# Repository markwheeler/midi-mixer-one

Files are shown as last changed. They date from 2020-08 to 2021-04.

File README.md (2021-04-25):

# MIDI Mixer One
MIDI Mixer One is a mixer-style USB MIDI controller built around Teensy.

[More info in the wiki](https://github.com/markwheeler/midi-mixer-one/wiki)

[Discussion thread on llllllll](https://llllllll.co/t/midi-mixer-one/35783)

Licensed under CC BY-NC-SA 4.0 (non-commercial use only).

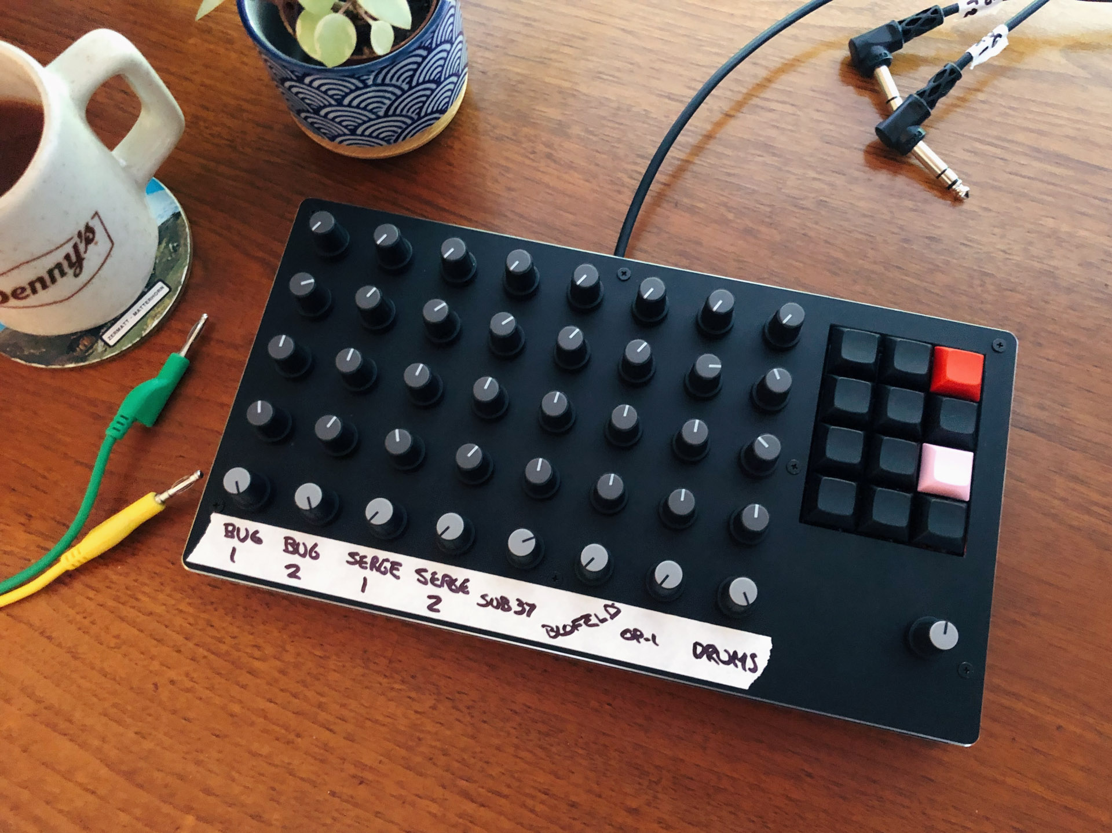
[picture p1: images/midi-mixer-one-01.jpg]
MIDI Mixer One photo


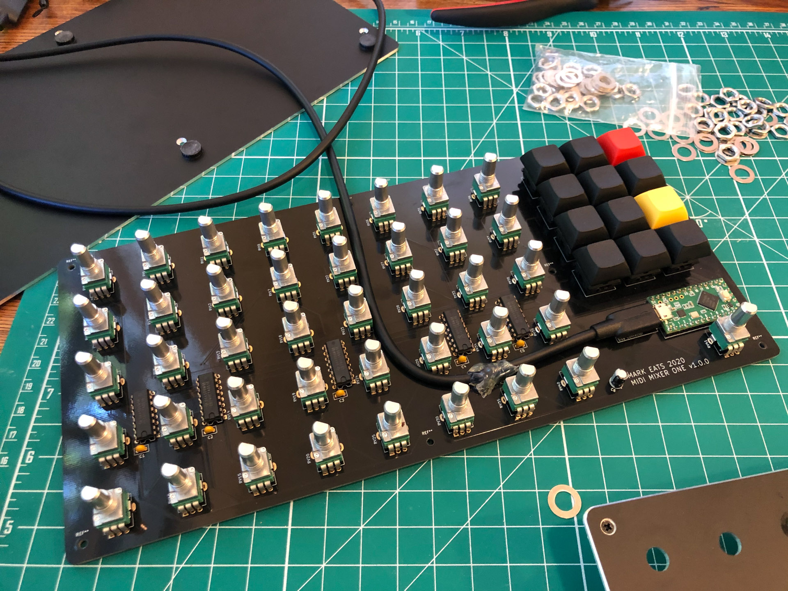
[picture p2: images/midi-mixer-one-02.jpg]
MIDI Mixer One build photo


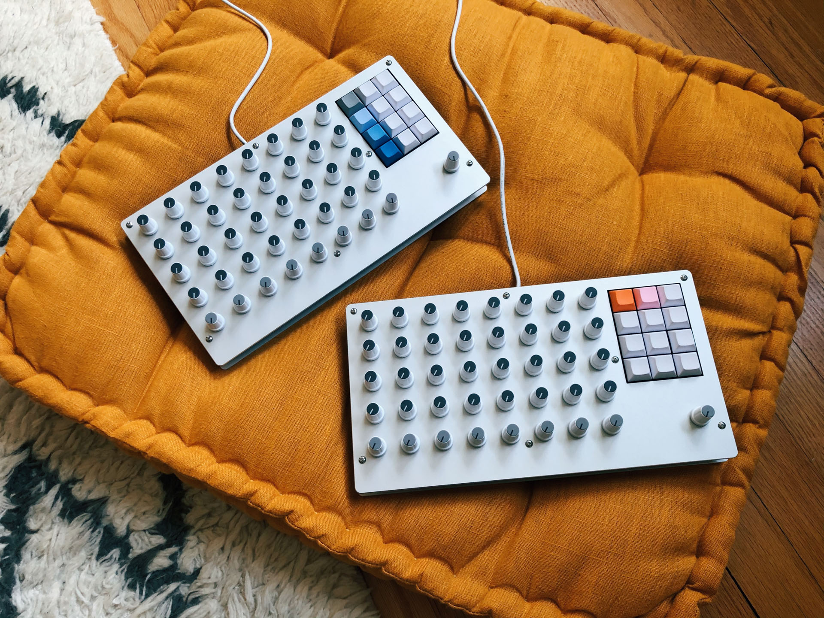
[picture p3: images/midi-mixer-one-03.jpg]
MIDI Mixer One photo


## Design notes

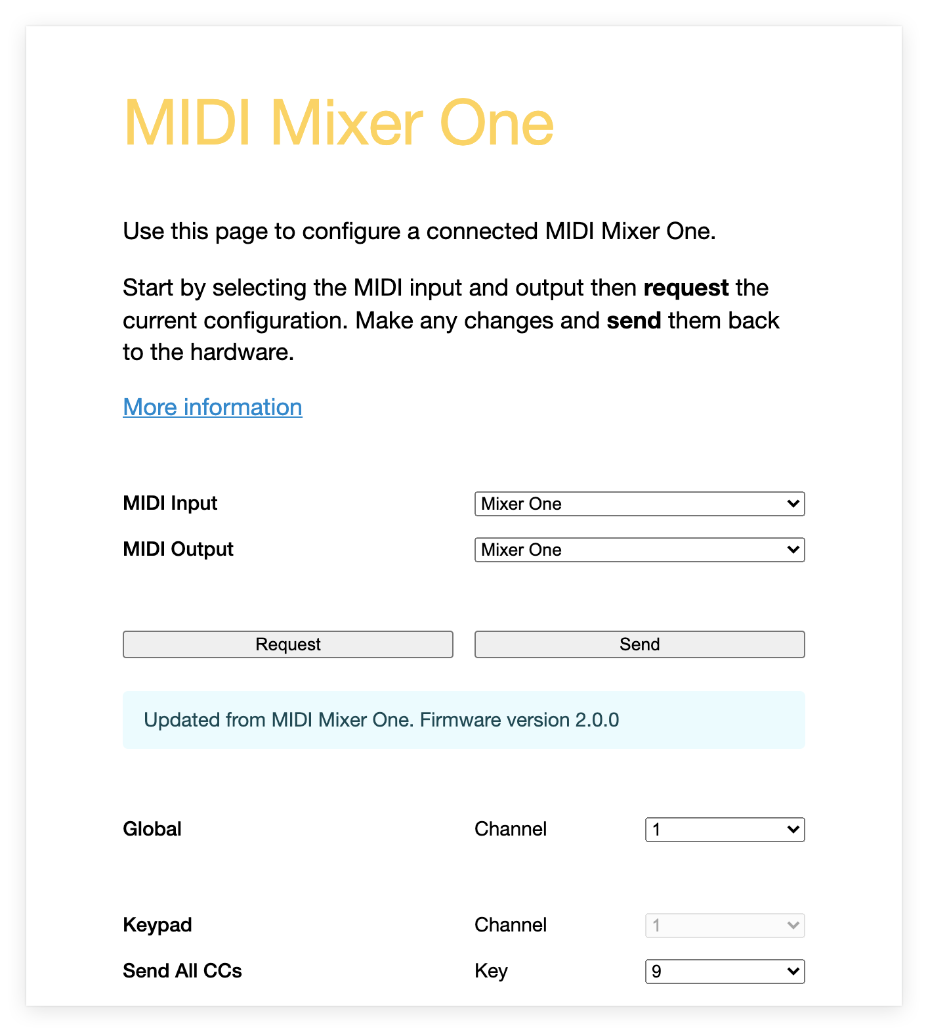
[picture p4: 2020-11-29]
images/web-config-01.png

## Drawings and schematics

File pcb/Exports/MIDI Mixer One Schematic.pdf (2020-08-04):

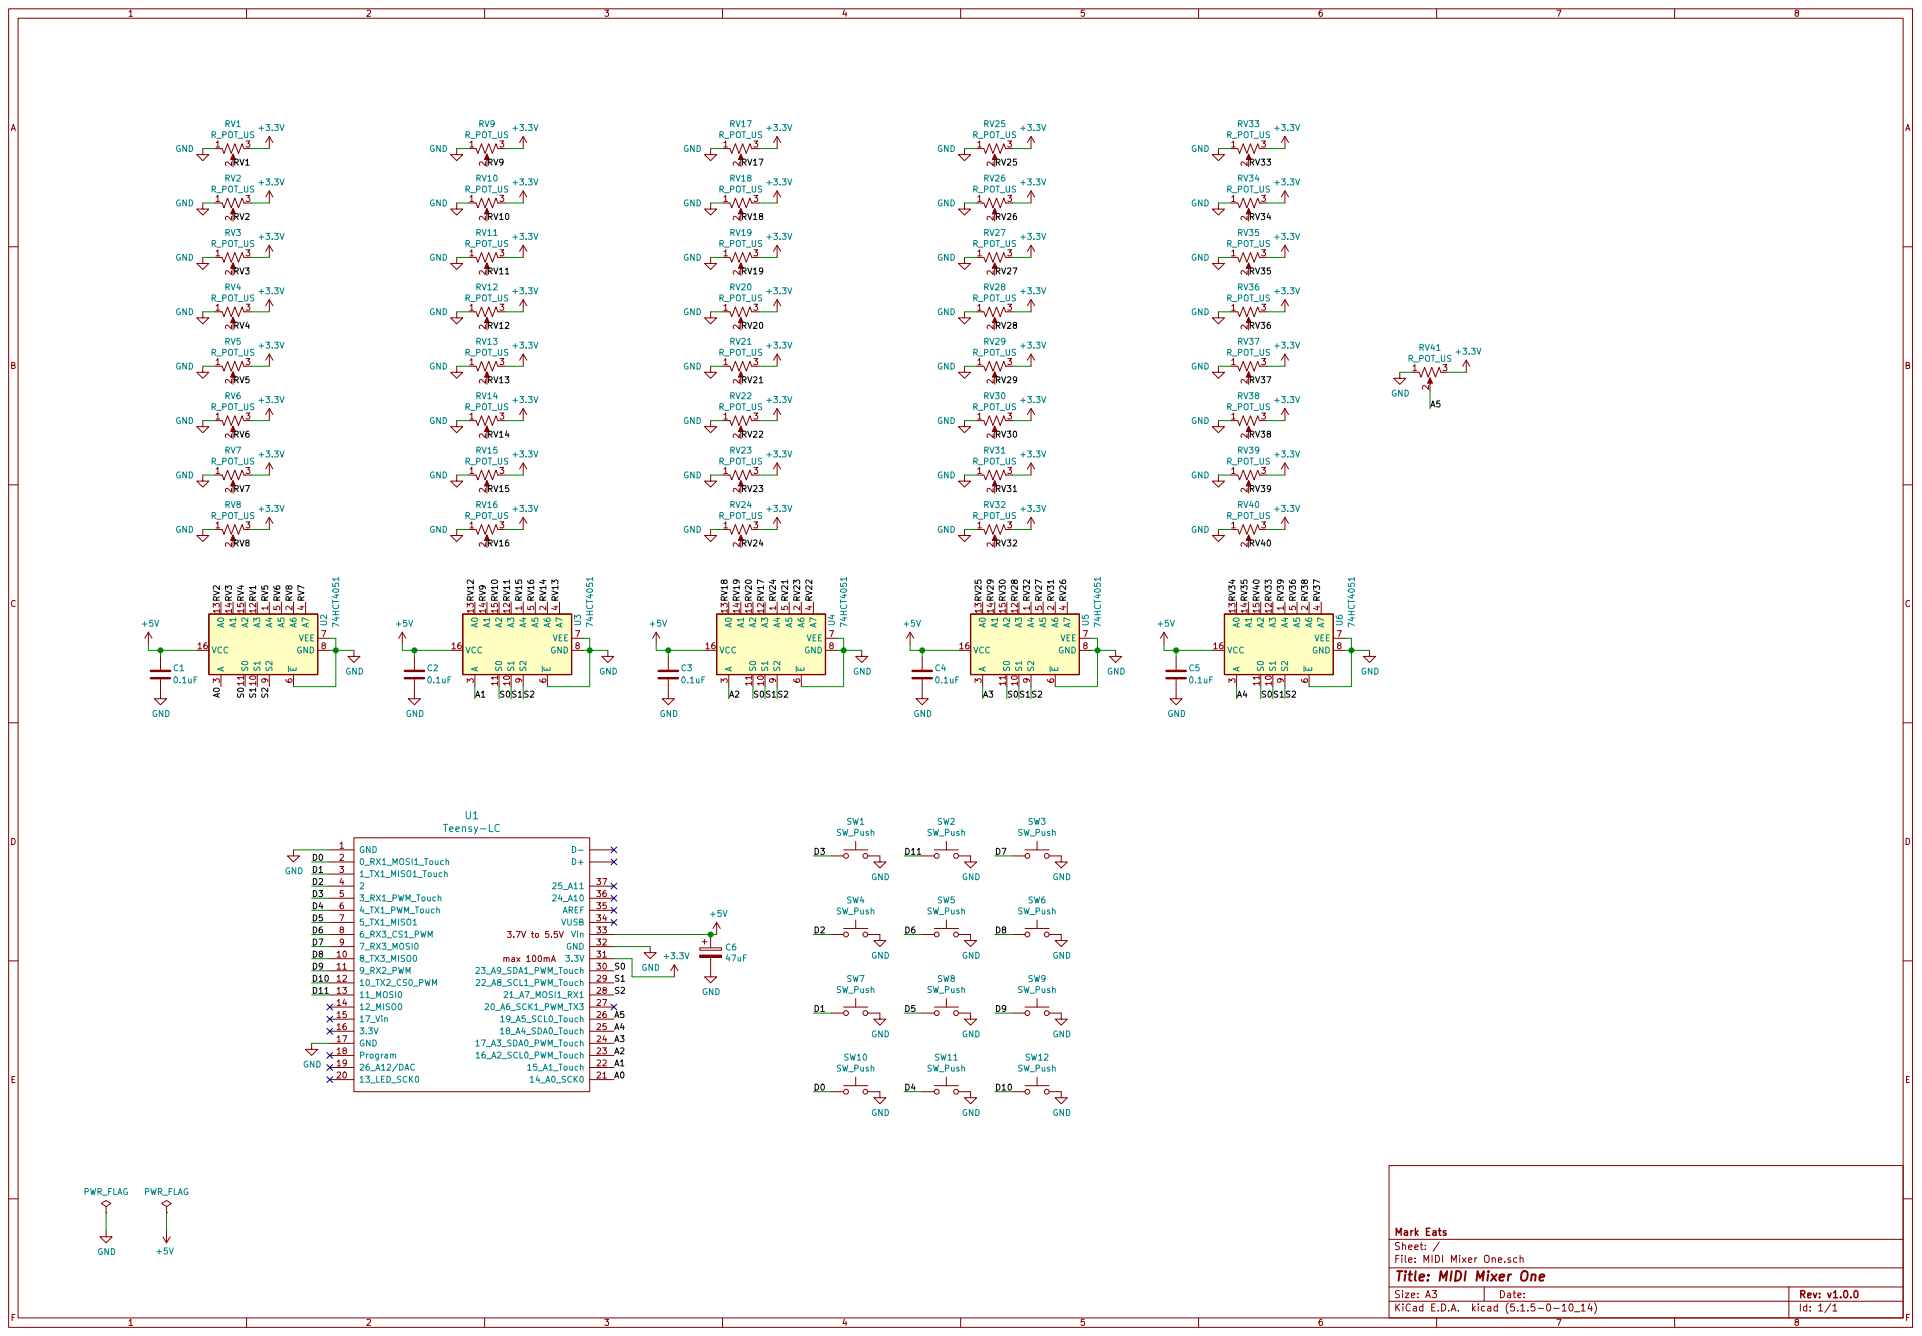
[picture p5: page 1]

3 RV1 R_POT_US
3 RV8 R_POT_US GND GND GND GND GND GND GND GND

3 RV9 R_POT_US
3 RV16 R_POT_US GND GND GND GND GND GND GND GND

+3.3V GND GND GND GND GND GND GND A4

File: MIDI Mixer One.sch Sheet: / Mark Eats

Id: 1/1 Title: MIDI Mixer One

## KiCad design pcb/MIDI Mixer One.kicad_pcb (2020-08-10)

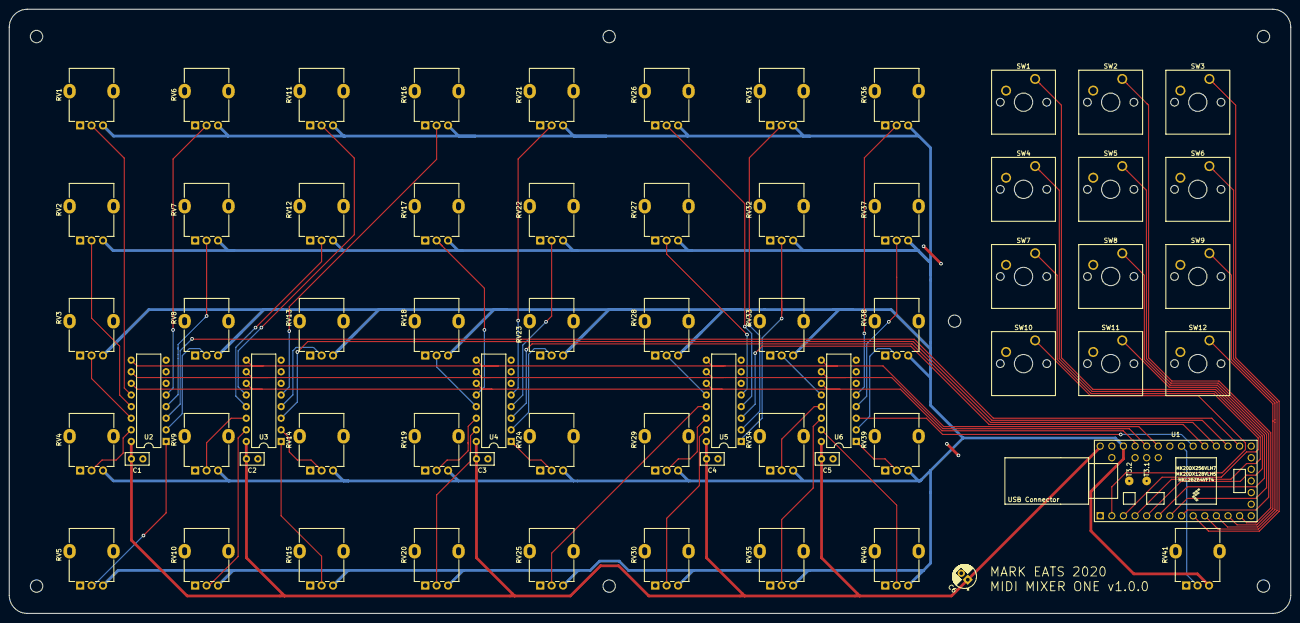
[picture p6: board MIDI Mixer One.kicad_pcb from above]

Board: 2 copper layers, 280.2 x 132.1 mm, 65 parts (0 on the bottom side), 64 nets.

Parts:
C1, C2, C3, C4, C5: 0.1uF; C_Disc_D5.0mm_W2.5mm_P2.50mm
C6: 47uF; CP_Radial_D5.0mm_P2.00mm
RV1, RV2, RV3, RV4, RV5, RV6, RV7, RV8, RV9, RV10, RV11, RV12, RV13, RV14, RV15, RV16, RV17, RV18, RV19, RV20, RV21, RV22, RV23, RV24, RV25, RV26, RV27, RV28, RV29, RV30, RV31, RV32, RV33, RV34, RV35, RV36, RV37, RV38, RV39, RV40, RV41: R_POT_US; Potentiometer_Alpha_RD901F-40-00D_Single_Vertical
SW1, SW2, SW3, SW4, SW5, SW6, SW7, SW8, SW9, SW10, SW11, SW12: SW_Push; SW_Cherry_MX_1.00u_PCB
U1: Teensy-LC; Teensy30_31_32_LC
U2, U3, U4, U5, U6: 74HCT4051; DIP-16_W7.62mm

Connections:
+3V3: RV1.3, RV2.3, RV3.3, RV4.3, RV5.3, RV6.3, RV7.3, RV8.3, RV9.3, RV10.3, RV11.3, RV12.3, RV13.3, RV14.3, RV15.3, RV16.3, RV17.3, RV18.3, RV19.3, RV20.3, RV21.3, RV22.3, RV23.3, RV24.3, RV25.3, RV26.3, RV27.3, RV28.3, RV29.3, RV30.3, RV31.3, RV32.3, RV33.3, RV34.3, RV35.3, RV36.3, RV37.3, RV38.3, RV39.3, RV40.3, RV41.3, U1.31
+5V: C1.2, C2.2, C3.2, C4.2, C5.2, C6.1, U1.33, U2.16, U3.16, U4.16, U5.16, U6.16
/A0: U1.21, U2.3
/A1: U1.22, U3.3
/A2: U1.23, U4.3
/A3: U1.24, U5.3
/A4: U1.25, U6.3
/A5: RV41.2, U1.26
/D0: SW10.1, U1.2
/D1: SW7.1, U1.3
/D2: SW4.1, U1.4
/D3: SW1.1, U1.5
/D4: SW11.1, U1.6
/D5: SW8.1, U1.7
/D6: SW5.1, U1.8
/D7: SW3.1, U1.9
/D8: SW6.1, U1.10
/D9: SW9.1, U1.11
/D10: SW12.1, U1.12
/D11: SW2.1, U1.13
/RV1: RV1.2, U2.12
/RV2: RV2.2, U2.13
/RV3: RV3.2, U2.14
/RV4: RV4.2, U2.15
/RV5: RV5.2, U2.1
/RV6: RV6.2, U2.5
/RV7: RV7.2, U2.4
/RV8: RV8.2, U2.2
/RV9: RV9.2, U3.14
/RV10: RV10.2, U3.15
/RV11: RV11.2, U3.12
/RV12: RV12.2, U3.13
/RV13: RV13.2, U3.4
/RV14: RV14.2, U3.2
/RV15: RV15.2, U3.1
/RV16: RV16.2, U3.5
/RV17: RV17.2, U4.12
/RV18: RV18.2, U4.13
/RV19: RV19.2, U4.14
/RV20: RV20.2, U4.15
/RV21: RV21.2, U4.5
/RV22: RV22.2, U4.4
/RV23: RV23.2, U4.2
/RV24: RV24.2, U4.1
/RV25: RV25.2, U5.13
/RV26: RV26.2, U5.4
/RV27: RV27.2, U5.5
/RV28: RV28.2, U5.12
/RV29: RV29.2, U5.14
/RV30: RV30.2, U5.15
/RV31: RV31.2, U5.2
/RV32: RV32.2, U5.1
/RV33: RV33.2, U6.12
/RV34: RV34.2, U6.13
/RV35: RV35.2, U6.14
/RV36: RV36.2, U6.5
/RV37: RV37.2, U6.4
/RV38: RV38.2, U6.2
/RV39: RV39.2, U6.1
/RV40: RV40.2, U6.15
/S0: U1.30, U2.11, U3.11, U4.11, U5.11, U6.11
/S1: U1.29, U2.10, U3.10, U4.10, U5.10, U6.10
/S2: U1.28, U2.9, U3.9, U4.9, U5.9, U6.9
GND: C1.1, C2.1, C3.1, C4.1, C5.1, C6.2, RV1.1, RV2.1, RV3.1, RV4.1, RV5.1, RV6.1, RV7.1, RV8.1, RV9.1, RV10.1, RV11.1, RV12.1, RV13.1, RV14.1, RV15.1, RV16.1, RV17.1, RV18.1, RV19.1, RV20.1, RV21.1, RV22.1, RV23.1, RV24.1, RV25.1, RV26.1, RV27.1, RV28.1, RV29.1, RV30.1, RV31.1, RV32.1, RV33.1, RV34.1, RV35.1, RV36.1, RV37.1, RV38.1, RV39.1, RV40.1, RV41.1, SW1.2, SW2.2, SW3.2, SW4.2, SW5.2, SW6.2, SW7.2, SW8.2, SW9.2, SW10.2, SW11.2, SW12.2, U1.1, U1.17, U1.32, U2.6, U2.7, U2.8, U3.6, U3.7, U3.8, U4.6, U4.7, U4.8, U5.6, U5.7, U5.8, U6.6, U6.7, U6.8

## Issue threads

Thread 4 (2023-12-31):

Idea: allow for an “Alt" key to make 3 layers of switch values

jasonbirchler, 2023-12-31:
hi 👋

I’m using midi-mixer-one with the 1010 Bluebox. I have 8 mixer channels assigned to the 8 columns of pots. I’d also like to be able to use 8 of the switches in 4 different “layers”. Allowing for one of the switches to act as an “Alt” key, in addition to the Shift key, would mean that 8 of the 10 remaining keys could easy map to each column of pots for things like Mute/Solo/Rec.

For example: key1 sends a CC that arms track 1 for rec, shift+key1 sends a CC that mutes track 1, alt+key1 sends a CC that solos track 1. Alt+Shift+key1 could also allow for a 4th layer and 40 total CC’s that could be sent via the switches. Or the Alt+Shift combo could be the “Send All CCs” command, for a total of 30 CC’s + Send All CC's

I forked the repo and started to code this, but quickly ran into an out of bounds error when trying to add the extra arrays for ```switchAltValues``` and ```switchAltShiftValues``` in ```serialize()``` and realized that I a) may have added more data than can be serialized, and b) don’t know jack squat about serializing MIDI data 😁

so before I go down a dark rabbit hole of trying to understand how MIDI data is sent over the wire, does this even sound possible? If so, does it sound like a worthwhile addition to the firmware? If so, I’m happy to contribute a PR adding the logic in the arduino code and necessary forms on the web-config tool. However, I may need some guidance on the un/serialize piece.

jason

markwheeler, 2024-01-01:
The serialization is really just to work around the limited EEPROM storage on the Teensy LC (1024 bits). It's not particularly elegant code but it means we can store as much as possible in that space by reducing all the values to the minimum number of bits required and then write them in byte-size chunks still using the `EEPROM.read/update` methods. TBH it might have been smarter to just create my own versions of those methods that do what we need but that's the solution I went with at the time :)

If you need to store significantly more data then it likely won't fit in the EEPROM but I think what you're describing would fit fine.

I'd suggest getting familiar with the JS code first because it's a bit more readable IMO. Take a look here to get an idea of the data structure: https://github.com/markwheeler/midi-mixer-one/blob/9becc82a8cd30aa25db95caa63e655ebd8a8d51b/web-config/js/Device.js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

If you get it all working, I'd be happy to have it in this repo!

jasonbirchler, 2024-01-04:
Thanks, that helps! I didn’t even think of looking at the JS to understand the data structure, and JS is what I’m most familiar with.

For my understanding, all of the de/serialization is to support programming via the web config, correct?

markwheeler, 2024-01-04:
yes, if you don't need configuration you could just hard code all the MIDI values and ignore the EEPROM.

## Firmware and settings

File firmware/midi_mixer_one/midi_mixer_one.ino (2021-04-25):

// MIDI Mixer One
// Mark Eats / Mark Wheeler
// Uses snippets from https://github.com/dxinteractive/ResponsiveAnalogRead/

const byte FIRMWARE_VERSION[] = {2, 1, 0};

#include <EEPROM.h>

// Pot params
#define POT_BITS                10 // 7-16 is valid
#define POT_NUM_READS           8 // 1-32 is reasonable
#define POT_SNAP_MULTIPLIER     0.1 // 0-1 lower values increase easing
#define POT_ACTIVITY_THRESHOLD  2 // Sleep zone

// Switch params
#define BOUNCE_LOCK_OUT
#define SWITCH_INTERVAL         5 // ms
#include <Bounce2.h>

// Hardware
#define NUM_POTS                41
#define NUM_MUXES               5
#define NUM_MUX_SIGNAL_PINS     3
#define NUM_MUX_CHANNELS        8
#define NUM_SWITCHES            12

const byte MUX_PINS[] =         {14, 15, 16, 17, 18};
const byte MUX_SIGNAL_PINS[] =  {23, 22, 21};
const byte MUX_POTS_BY_CHANNEL[][NUM_MUX_CHANNELS] = {
  {1, 2, 3, 0, 4, 5, 7, 6},
  {11, 8, 9, 10, 14, 15, 13, 12},
  {17, 18, 19, 16, 23, 20, 22, 21},
  {24, 28, 29, 27, 31, 26, 30, 25},
  {33, 34, 39, 32, 38, 35, 37, 36},
};
#define MIX_POT_PIN             19
const byte SWITCH_PINS[] =      {3, 11, 7, 2, 6, 8, 1, 5, 9, 0, 4, 10};

const int POT_RES = pow(2, POT_BITS);

// Sysex and config store
const byte MANUFACTURER_ID[] =  {0x7D, 0x00, 0x00};
#define MODEL_ID                0
#define PROTOCOL_VERSION        1
#define SYSEX_START_CODE        0xF0
#define SYSEX_END_CODE          0xF7
#define REQUEST                 0x00
#define REQUEST_LENGTH          8
#define STORE                   0x01
#define STORE_HEADER_LENGTH     8
#define RESPONSE                0x02
#define RESPONSE_HEADER_LENGTH  9
#define WRITE_FAILED            0x03
#define WRITE_FAILED_LENGTH     6
const byte SYSEX_RESPONSE_HEADER[] = {MANUFACTURER_ID[0], MANUFACTURER_ID[1], MANUFACTURER_ID[2], MODEL_ID, PROTOCOL_VERSION, RESPONSE,
                                      FIRMWARE_VERSION[0], FIRMWARE_VERSION[1], FIRMWARE_VERSION[2]
                                     };
const byte SYSEX_WRITE_FAILED[] = {MANUFACTURER_ID[0], MANUFACTURER_ID[1], MANUFACTURER_ID[2], MODEL_ID, PROTOCOL_VERSION, WRITE_FAILED};

#define UNPACKED_BYTE_DATA_LENGTH 121
#define PACKED_BYTE_DATA_LENGTH   92
#define BIN_DATA_LENGTH           644
byte dataBitsArray[UNPACKED_BYTE_DATA_LENGTH];

// Vars
byte potChannels[NUM_POTS];
byte potCCs[NUM_POTS];
byte switchChannel;
byte switchTypes[NUM_SWITCHES];
byte switchValues[NUM_SWITCHES];
byte switchShiftValues[NUM_SWITCHES];
byte shiftSwitch; // 0 for none
byte sendAllSwitch; // 0 for none
bool shiftActive = false;
bool downSwitches[NUM_SWITCHES] = {false};

float potValues[NUM_POTS];
byte potMidiValues[NUM_POTS];
Bounce switches[NUM_SWITCHES];

byte incomingSysex[PACKED_BYTE_DATA_LENGTH + STORE_HEADER_LENGTH];
int incomingSysexLength = 0;

void setup() {

  Serial.begin(38400);

  analogReadResolution(POT_BITS);
  analogReadAveraging(POT_NUM_READS);

  // Pots
  for (byte i = 0; i < NUM_MUX_SIGNAL_PINS; i ++) {
    pinMode(MUX_SIGNAL_PINS[i], OUTPUT);
  }

  // Switches
  for (byte i = 0; i < NUM_SWITCHES; i ++) {
    pinMode(SWITCH_PINS[i], INPUT_PULLUP);
    switches[i] = Bounce();
    switches[i].attach(SWITCH_PINS[i]);
    switches[i].interval(SWITCH_INTERVAL);
  }

  // LED
  pinMode(LED_BUILTIN, OUTPUT);
  digitalWrite(LED_BUILTIN, HIGH);

  generateDataBitsArray();
  unserialize(readEeprom());

  usbMIDI.setHandleSystemExclusive(processSysexChunk);
}

void sendAllPotValues() {
  for (byte i = 0; i < NUM_POTS; i ++) {
    usbMIDI.sendControlChange(potCCs[i], potMidiValues[i], potChannels[i] + 1);
  }
}

float snapCurve(float x) {
  float y = 1.0 / (x + 1.0);
  y = (1.0 - y) * 2.0;
  if (y > 1.0) {
    return 1.0;
  }
  return y;
}

float smoothValue(float oldValue, int newValue) {

  int diff = abs(newValue - oldValue);

  if (diff < POT_ACTIVITY_THRESHOLD) {
    return oldValue;
  }

  float snap = snapCurve(diff * POT_SNAP_MULTIPLIER);
  return oldValue + (newValue - oldValue) * snap;
}

void readPots() {

  // Read pots on muxes
  for (byte c = 0; c < NUM_MUX_CHANNELS; c ++) {

    // Set mux channel
    for (byte s = 0; s < NUM_MUX_SIGNAL_PINS; s ++) {
      digitalWrite(MUX_SIGNAL_PINS[s], bitRead(c, s));
    }
    delayMicroseconds(5);

    // Read from all muxes
    for (byte m = 0; m < NUM_MUXES; m ++) {
      byte pot = MUX_POTS_BY_CHANNEL[m][c];
      potValues[pot] = smoothValue(potValues[pot], analogRead(MUX_PINS[m]));
    }
  }

  // Read mix pot
  potValues[40] = smoothValue(potValues[40], analogRead(MIX_POT_PIN));

  // Check values
  for (byte i = 0; i < NUM_POTS; i ++) {

    byte newMidiValue = int(potValues[i] + 0.5) >> (POT_BITS - 7);

    if (newMidiValue != potMidiValues[i]) {
      usbMIDI.sendControlChange(potCCs[i], newMidiValue, potChannels[i] + 1);
      potMidiValues[i] = newMidiValue;
    }
  }
}

byte getSwitchValue(byte index) {
  byte switchValue;
  if (shiftActive) {
    switchValue = switchShiftValues[index];
  } else {
    switchValue = switchValues[index];
  }
  return switchValue;
}

void switchDown(byte index) {
  downSwitches[index] = true;
  if (switchTypes[index]) {
    usbMIDI.sendControlChange(getSwitchValue(index), 127, switchChannel + 1);
  } else {
    usbMIDI.sendNoteOn(getSwitchValue(index), 127, switchChannel + 1);
  }
}

void switchUp(byte index) {
  if (downSwitches[index]) {
    downSwitches[index] = false;
    if (switchTypes[index]) {
      usbMIDI.sendControlChange(getSwitchValue(index), 0, switchChannel + 1);
    } else {
      usbMIDI.sendNoteOff(getSwitchValue(index), 0, switchChannel + 1);
    }
  }
}

void switchesAllUp() {
  for (int k = 0; k < NUM_SWITCHES; k ++) {
    switchUp(k);
  }
}

void readSwitches() {

  for (byte i = 0; i < NUM_SWITCHES; i ++) {
    switches[i].update();

    // Shift
    if (i == shiftSwitch - 1) {
      if (switches[i].fell()) {
        switchesAllUp();
        shiftActive = true;
      } else if (switches[i].rose()) {
        switchesAllUp();
        shiftActive = false;
      }

    // Send all pot values
    } else if ((!shiftActive && i == sendAllSwitch - 1) || (shiftActive && i == sendAllSwitch - 13)) {
      if (switches[i].fell()) {
        sendAllPotValues();
      }

    // Send switches
    } else {
      if (switches[i].fell()) {
        switchDown(i);
      } else if (switches[i].rose()) {
        switchUp(i);
      }
    }

  }
}

byte* readEeprom() {
  static byte serialData[PACKED_BYTE_DATA_LENGTH];
  for (unsigned i = 0; i < PACKED_BYTE_DATA_LENGTH; i ++) {
    serialData[i] = EEPROM.read(i);
  }
  return serialData;
}

bool writeEeprom(byte* serialData) {
  bool success = true;

  for (unsigned i = 0; i < PACKED_BYTE_DATA_LENGTH; i ++) {
    EEPROM.update(i, serialData[i]);

    // NOTE: Checking every byte here, ideally remove in future if EEPROM.update() is proven reliable.
    if (success && EEPROM.read(i) != serialData[i]) {
      success = false;
    }
  }

  Serial.print("EEPROM write success ");
  Serial.println(success);

  return success;
}

void generateDataBitsArray() {

  unsigned p = 0;

  // 4bit potChannel, 7bit potCC
  for (unsigned i = 0; i < NUM_POTS; i++) {
    dataBitsArray[p] = 4;
    p ++;
    dataBitsArray[p] = 7;
    p ++;
  }

  // 1bit switchType, 7bit switchValue, 7bit switchShiftValue
  for (unsigned i = 0; i < NUM_SWITCHES; i++) {
    dataBitsArray[p] = 1;
    p ++;
    dataBitsArray[p] = 7;
    p ++;
    dataBitsArray[p] = 7;
    p ++;
  }

  // 4bit switchChannel, 4bit shiftSwitch, 5bit sendAllSwitch
  dataBitsArray[p] = 4;
  p ++;
  dataBitsArray[p] = 4;
  p ++;
  dataBitsArray[p] = 5;

}

bool* arrayToBits(byte* serialData, unsigned serialDataLength, bool useDataBitsArray = false, byte bitSize = 7) {

  // Accepts uints 1 to 8 bits

  static bool binArray[BIN_DATA_LENGTH];

  unsigned pos = 0;
  for (unsigned i = 0; i < serialDataLength; i ++) {

    if (useDataBitsArray) {
      bitSize = dataBitsArray[i];
    }
    byte number = serialData[i];
    for (unsigned j = 0; j < bitSize; j ++) {
      binArray[pos + bitSize - 1 - j] = number & 0b00000001;
      number >>= 1;
    }

    pos += bitSize;
  }

  return binArray;
}

byte* bitsToNumberArray(bool* bitsData, bool useDataBitsArray = false, byte bitSize = 7) {

  static byte byteArray[UNPACKED_BYTE_DATA_LENGTH];

  unsigned pos = 0;

  for (unsigned i = 0; i < BIN_DATA_LENGTH; i += 0) {

    if (useDataBitsArray) {
      bitSize = dataBitsArray[pos];
    }

    byte number = 0;
    for (unsigned j = 0; j < bitSize; j ++) {
      number <<= 1;
      number |= bitsData[i + j];
    }
    byteArray[pos] = number;

    i += bitSize;
    pos ++;
  }

  return byteArray;
}

byte* serialize() {

  byte serialData[UNPACKED_BYTE_DATA_LENGTH];
  unsigned a = 0;

  for (unsigned i = 0; i < NUM_POTS; i ++) {
    serialData[a] = potChannels[i];
    serialData[a + 1] = potCCs[i];
    a += 2;
  }

  for (unsigned i = 0; i < NUM_SWITCHES; i ++) {
    serialData[a] = switchTypes[i];
    serialData[a + 1] = switchValues[i];
    serialData[a + 2] = switchShiftValues[i];
    a += 3;
  }

  serialData[a] = switchChannel;
  a ++;
  serialData[a] = shiftSwitch;
  a ++;
  serialData[a] = sendAllSwitch;

  // Generate an array that is a binary array of all the data
  bool* binArray = arrayToBits(serialData, UNPACKED_BYTE_DATA_LENGTH, true);
  // Split that array into bytes
  byte* byteArray = bitsToNumberArray(binArray, false, 7);

  return byteArray;
}

void unserialize(byte* serialData) {

  // Turn the byte array into a binary array
  bool* unserializedBinArray = arrayToBits(serialData, PACKED_BYTE_DATA_LENGTH, false, 7);
  // Unserialize that binary array into data of varying bit lengths
  byte* unserialized = bitsToNumberArray(unserializedBinArray, true);


  const byte SWITCHES_DATA_START = NUM_POTS * 2;
  const byte EXTRA_DATA_START = SWITCHES_DATA_START + NUM_SWITCHES * 3;

  // Pot channels and CCs
  unsigned potIndex = 0;
  for (unsigned i = 0; i < SWITCHES_DATA_START; i += 2) {
    potChannels[potIndex] = constrain(unserialized[i], 0, 15);
    potCCs[potIndex] = constrain(unserialized[i + 1], 0, 127);
    potIndex ++;
  }

  // Switch notes
  unsigned switchIndex = 0;
  for (unsigned i = SWITCHES_DATA_START; i < EXTRA_DATA_START; i += 3) {
    switchTypes[switchIndex] = constrain(unserialized[i], 0, 1);
    switchValues[switchIndex] = constrain(unserialized[i + 1], 0, 127);
    switchShiftValues[switchIndex] = constrain(unserialized[i + 2], 0, 127);
    switchIndex ++;
  }

  switchChannel = constrain(unserialized[EXTRA_DATA_START], 0, 15);
  shiftSwitch = constrain(unserialized[EXTRA_DATA_START + 1], 0, 12);
  sendAllSwitch = constrain(unserialized[EXTRA_DATA_START + 2], 0, 24);

}

void processSysexChunk(const byte* sysexData, uint16_t length, bool last) {

  if (incomingSysexLength + length <= PACKED_BYTE_DATA_LENGTH + STORE_HEADER_LENGTH ) {

    memcpy(incomingSysex + incomingSysexLength * sizeof(byte), sysexData, length);
    incomingSysexLength += length;

    if (last) {
      processSysex(incomingSysex, incomingSysexLength);
      incomingSysexLength = 0;
    }

  } else {
    Serial.println("Oversize sysex received");
    incomingSysexLength = 0;
  }

}

void processSysex(const byte* sysexData, uint16_t length) {

  // Format should be: SYSEX_START_CODE, MANUFACTURER_ID x3, MODEL_ID, PROTOCOL_VERSION, command, dataArray, SYSEX_END_CODE

  // Check length
  if (length > 7) {

    // Check for start and end
    if (sysexData[0] == SYSEX_START_CODE && sysexData[length - 1] == SYSEX_END_CODE) {

      // Check manufacturer, model
      if (sysexData[1] == MANUFACTURER_ID[0] && sysexData[2] == MANUFACTURER_ID[1] && sysexData[3] == MANUFACTURER_ID[2]
          && sysexData[4] == MODEL_ID) {

        // Check protocol
        if (sysexData[5] != PROTOCOL_VERSION) {
          Serial.println("Incompatible protocol");
          sendSysexProtocolVersion();

        } else {

          // Request
          if (sysexData[6] == REQUEST && length == REQUEST_LENGTH) {
            Serial.println("Sysex request");
            sendSysexConfig();

          // Store
          } else if (sysexData[6] == STORE && length == PACKED_BYTE_DATA_LENGTH + STORE_HEADER_LENGTH) {
            Serial.println("Sysex store");
            storeSysexConfig(sysexData);

          } else {
            Serial.println("Unknown sysex command");
          }
        }
      }
    }
  }
}

void sendSysexProtocolVersion() {
  usbMIDI.sendSysEx(RESPONSE_HEADER_LENGTH, SYSEX_RESPONSE_HEADER, false);
}

void sendSysexConfig() {

  byte sysexData[PACKED_BYTE_DATA_LENGTH + RESPONSE_HEADER_LENGTH];
  byte* configData = serialize();

  memcpy(sysexData, SYSEX_RESPONSE_HEADER, RESPONSE_HEADER_LENGTH * sizeof(byte));
  memcpy(sysexData + RESPONSE_HEADER_LENGTH * sizeof(byte), configData, PACKED_BYTE_DATA_LENGTH * sizeof(byte));

  usbMIDI.sendSysEx(RESPONSE_HEADER_LENGTH + PACKED_BYTE_DATA_LENGTH, sysexData, false);
}

void sendWriteFailed() {
  usbMIDI.sendSysEx(WRITE_FAILED_LENGTH, SYSEX_WRITE_FAILED, false);
}

void storeSysexConfig(const byte* sysexData) {

  byte trimmedData[PACKED_BYTE_DATA_LENGTH];
  memcpy(trimmedData, sysexData + STORE_HEADER_LENGTH * sizeof(byte) - 1, PACKED_BYTE_DATA_LENGTH * sizeof(byte));

  unserialize(trimmedData);

  if (!writeEeprom(trimmedData)) {
    sendWriteFailed();
  }
}

void loop() {

//  unsigned long startTime = micros();

  readPots();
  readSwitches();

  while (usbMIDI.read()) {
  }

  delay(2); // ms (~300 fps)

//  Serial.println(1000000 / (micros() - startTime));

}

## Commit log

2020-08-04 cleanup old versions
    [MIDI Mixer One v01.kicad_pcb, MIDI Mixer One v01.sch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]
2020-08-04 cleanup kicad libs and cache files
    [MIDI Mixer One.sch]
2020-08-10 removed REF text from silk screen
    [MIDI Mixer One-B_Cu.gbr, MIDI Mixer One-B_Mask.gbr, MIDI Mixer One-B_Paste.gbr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]
2020-10-28 defaults button etc
2020-11-05 switched to events, global channel, defaults
2020-11-05 start of sysex processing on teensy
2020-11-28 filter input and only update ports when need be
2020-11-28 remove dummy response button
